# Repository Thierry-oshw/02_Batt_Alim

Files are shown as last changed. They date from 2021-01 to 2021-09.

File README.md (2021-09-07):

# 02_Batt_Alim

Le module Batt_Alim permet de gérer la charge d'une batterie Lipo constituée d'une seule cellule (4.2V) à partir d'une source de type 5V USB.
Il permet aussi de récupérer cette tension batterie variable et de reconstituer un 5V constant grâce à un DCDC.

La licence est celle du CERN Open Hardware Licence version 2; CERN-OHL-P ; permissive.
Le fichier de cette license est présent dans le répertoire: cern_ohl_p_v2.txt

# Photos

Ci-joint la photo de la version de 2021_06_04 // Here picture of version 2021_06_04:

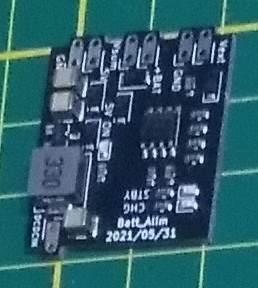
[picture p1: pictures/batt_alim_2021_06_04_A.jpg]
02_Batt_Alim photo du dessus du module version 2021_06_04. Errata: cette fabriquation présente le 2021_05_31 sur le pcb.


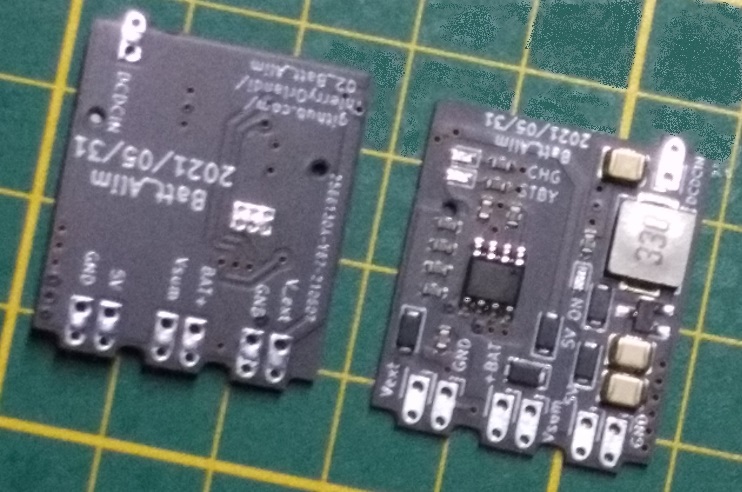
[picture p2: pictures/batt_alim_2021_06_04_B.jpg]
02_Batt_Alim photo des dessous et dessus du module version 2021_06_04. Errata: cette fabriquation présente le 2021_05_31 sur le pcb.


# Schéma et fonctionnement

Ci-joint le schéma de la version de 2021_06_04 // Here schematic of version 2021_06_04:
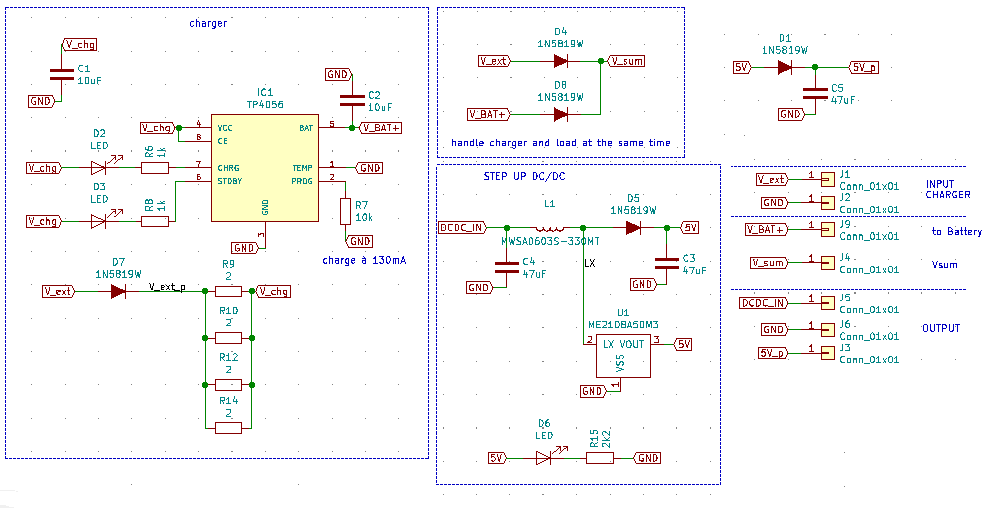
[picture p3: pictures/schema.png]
02_Batt_Alim schéma du module


Le module fonctionne de la façon suivante:
Il faut l'alimenter avec une tension 5V +-5% (typiquement celle de l'USB classique) sur la pin Vext. (Ne pas oublier GND bien sûr).

Il faut brancher la batterie Lipo sur V_bat+ et GND. La batterie Lipo doit être constituée d'une seule cellule, qui doit être chargée à 4.2V, présente une tension de 3.7V typique, et dont la tension de mise en protection est de 3V. La résistance R7 de 10kOhms permet de régler la puce TP4056 sur un courant de charge de 130mA. La batterie Lipo doit donc avoir une capacité d'au moins 2*130mAh, soit 260mAh au minimum. Plus d'information sur www.tp4056.com.

La sortie V_sum est à relier à DCDC_IN (ceci permet d'insérer un interrupteur à cet endroit).

La sortie 5V_p est une tension issue du DCDC qui est filtrée et protégée par la diode D1 et le condensateur C5.

La LED D6 indique la présence de 5V à la sortie du DCDC, avec "5V ON" comme étiquette.

Les LEDs D2 et D3 indiquent respectivement la charge et le mode standby du TP4056. Les étiquettes sont "CHG" et "STBY".

# Archives:

Ci-joint la photo de la version de 2020_12_22 // Here picture of version 2020_12_22:
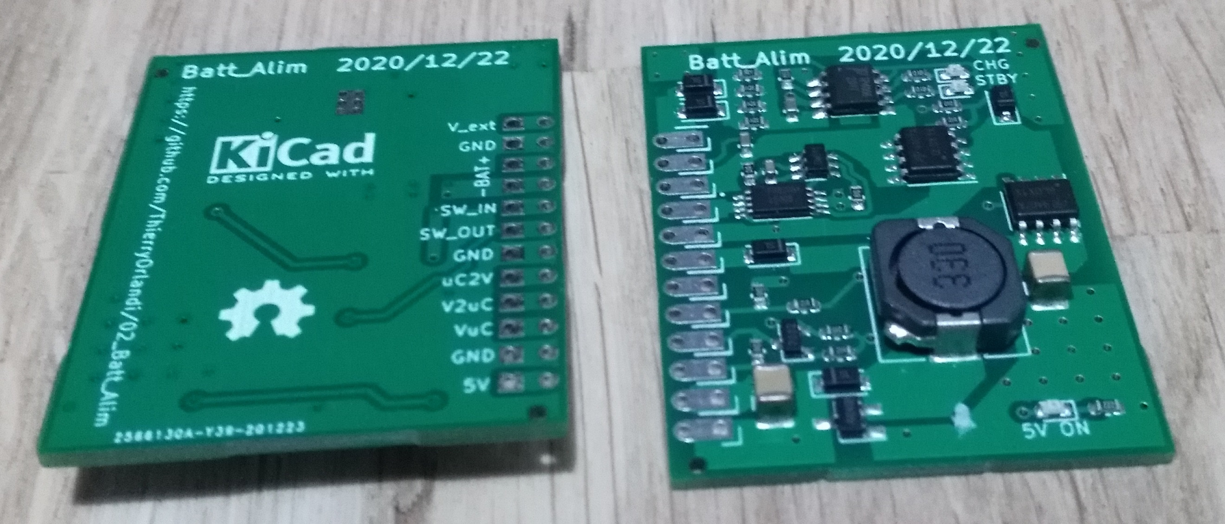
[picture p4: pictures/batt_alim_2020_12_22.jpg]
02_Batt_Alim photo dessous et dessus du module version 2020_12_22


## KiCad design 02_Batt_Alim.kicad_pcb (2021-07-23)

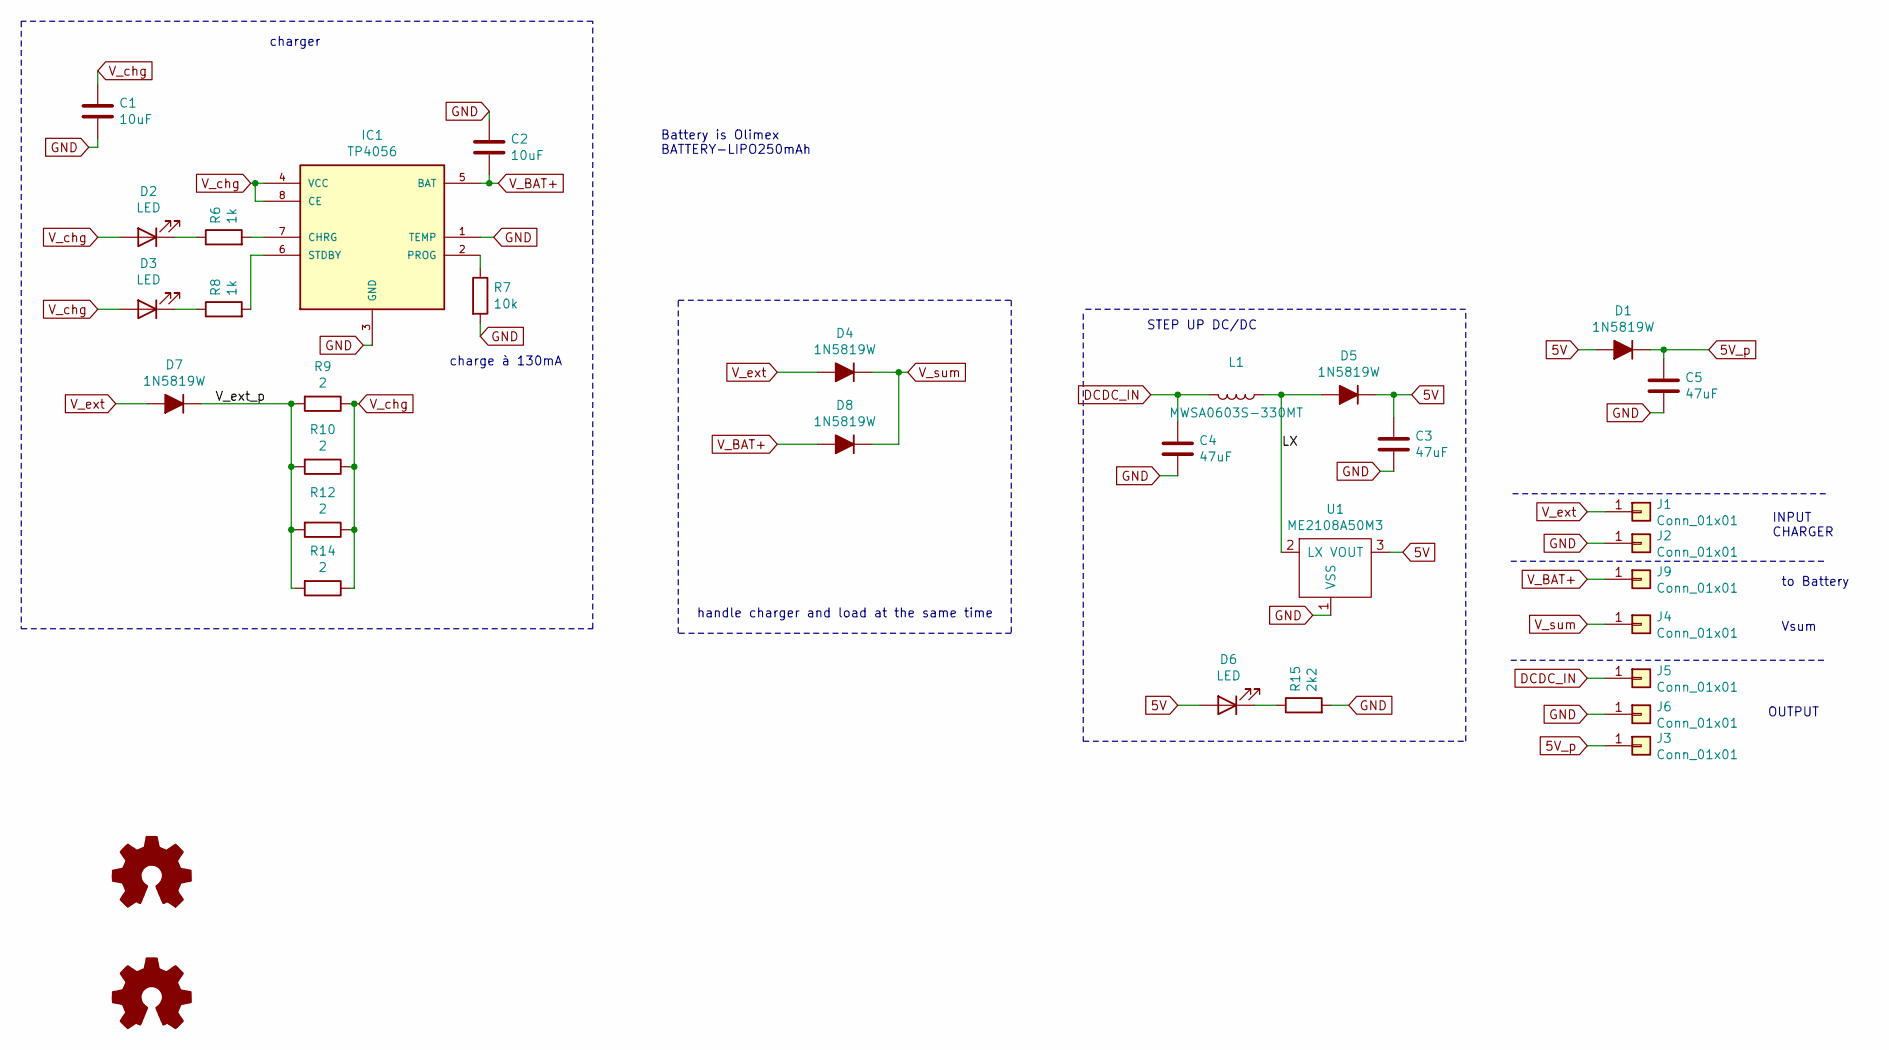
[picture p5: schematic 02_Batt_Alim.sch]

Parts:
C1, C2: 10uF; C_0603_1608Metric
C3, C4, C5: 47uF; C_1210_3225Metric
D1, D4, D5, D7, D8: 1N5819W; D_SOD-123F
D2, D3, D6: LED; D_0603_1608Metric
IC1: TP4056; SOP-8
J1, J2, J3, J4, J5, J6, J9: Conn_01x01; Castellated_conn
L1: MWSA0603S-330MT; L_Sunlord_MWSA0603S_6.6x7.0x2.8mm
R6, R8: 1k; R_0603_1608Metric
R7: 10k; R_0603_1608Metric
R9, R10, R12, R14: 2; R_0603_1608Metric
R15: 2k2; R_0603_1608Metric
U1: ME2108A50M3; SOT-23_Handsoldering

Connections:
5V: C3.1, D1.2 (A), D5.1 (K), D6.2 (A), U1.3 (VOUT)
5V_p: C5.1, D1.1 (K), J3.1
/LX: D5.2 (A), L1.1, U1.2 (LX)
/V_ext_p: D7.1 (K), R9.2, R10.2, R12.2, R14.2
DCDC_IN: C4.1, J5.1, L1.2
GND: C1.2, C2.1, C3.2, C4.2, C5.2, IC1.1 (TEMP), IC1.3 (GND), J2.1, J6.1, R7.2, R15.2, U1.1 (VSS)
unnamed: D2.1 (K), R6.1
unnamed: D3.1 (K), R8.1
unnamed: D6.1 (K), R15.1
unnamed: IC1.2 (PROG), R7.1
unnamed: IC1.6 (STDBY), R8.2
unnamed: IC1.7 (CHRG), R6.2
V_BAT+: C2.2, D8.2 (A), IC1.5 (BAT), J9.1
V_chg: C1.1, D2.2 (A), D3.2 (A), IC1.4 (VCC), IC1.8 (CE), R9.1, R10.1, R12.1, R14.1
V_ext: D4.2 (A), D7.2 (A), J1.1
V_sum: D4.1 (K), D8.1 (K), J4.1

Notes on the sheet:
Battery is Olimex BATTERY-LIPO250mAh
INPUT CHARGER
OUTPUT
STEP UP DC/DC
handle charger and load at the same time
charger
charge à 130mA
to Battery
Vsum

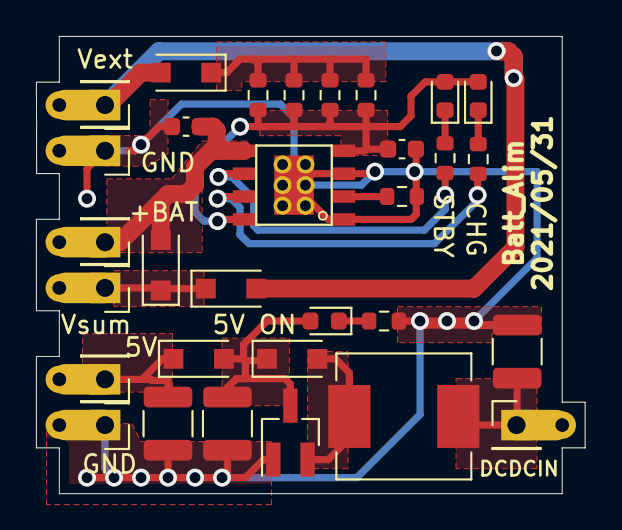
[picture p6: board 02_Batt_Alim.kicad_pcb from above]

Board: 2 copper layers, 30.5 x 25.4 mm, 31 parts (0 on the bottom side), 16 nets.

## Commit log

2020-12-06 gitignore set to kicad version
2020-12-13 saisie du schéma + placement + premier routage
    [02_Batt_Alim.kicad_pcb, 02_Batt_Alim.sch]
2020-12-14 dernières modification et routage avec plan de cuivre
    [02_Batt_Alim.kicad_pcb, 02_Batt_Alim.sch]
2020-12-16 corrected diodes schematics; gerbers generation
    [02_Batt_Alim-B_Cu.gbr, 02_Batt_Alim-B_Fab.gbr, 02_Batt_Alim-B_Mask.gbr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]
2020-12-16 added kicad et oshw logos
    [02_Batt_Alim-B_Cu.gbr, 02_Batt_Alim-B_Fab.gbr, 02_Batt_Alim-B_Mask.gbr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]
2020-12-19 ajout logo kicad
    [02_Batt_Alim.kicad_pcb]
2021-02-06 simplify!
    1) battery lipo protection deleted
    2) move to schottky diodes instead of pmos for avoiding perturbation of charge while switch is on.
    3) reduced size of pcb
    4) added nmos for "hold" function
    [02_Batt_Alim.kicad_pcb, 02_Batt_Alim.sch]
2021-02-22 simplification
    simplified the whole design
    Gerbers generated
    [02_Batt_Alim-B_Cu.gbr, 02_Batt_Alim-B_Fab.gbr, 02_Batt_Alim-B_Mask.gbr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]
2021-02-22 mechanical dimensions added
    [02_Batt_Alim.kicad_pcb]
2021-05-21 coupé en deux
    séparé la partie dcdc du chargeur;
    schéma fait et routage en cours de modification
    [02_Batt_Alim.kicad_pcb, 02_Batt_Alim.sch]
2021-05-28 modifications
    ajout diode + capa pour filtrer + protection en sortie
    changement inductance
    [02_Batt_Alim.kicad_pcb, 02_Batt_Alim.sch]
2021-05-31 modifications
    - passage SOP8 en CMS
    - schéma correction ref 10k
    [02_Batt_Alim.kicad_pcb, 02_Batt_Alim.sch]
2021-07-23 changed to new library
    [02_Batt_Alim.sch]
2021-07-23 changement librairie Chimère split
    [02_Batt_Alim.kicad_pcb, 02_Batt_Alim.sch]
